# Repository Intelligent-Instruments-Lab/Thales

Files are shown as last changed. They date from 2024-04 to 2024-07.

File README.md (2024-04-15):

# Thales
Software, 3D model and printing files, hardware specs and instructions for building Thales.

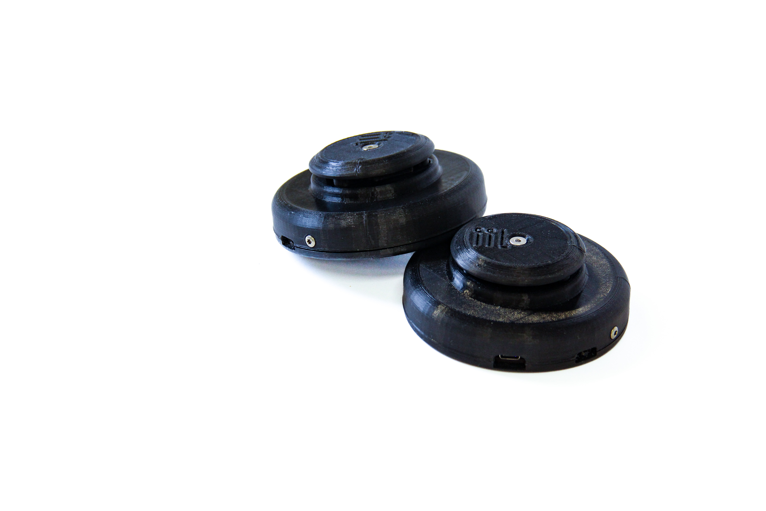
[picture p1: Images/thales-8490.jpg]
  

Hardware: 
- 1x Receiver: I use Esp32 TTGO V7 1.3 Mini - you can use any ESP32 board.
- 2x Sender (on board microcontrollers): Adafruit ESP32 Pico Stemma QT - S2 (avoid S3 due to incompatibility with the BNO055) (https://www.adafruit.com/product/5325)
- 2x Battery Charger shields for Stemma QT (https://www.adafruit.com/product/5397)
- 2x Adafruit BNO055 (https://www.adafruit.com/product/4646)
- Taidacent MLX90393 (with few mods should easily host the Adafruit version)
- 4x Stemma QT I2C wires
- 2x SPDT Switch: https://www.adafruit.com/product/805
- Set of neodymium magnets, 30mm diameter (4mm thick ones, but also 5mm is fine)
- 2x LiPo batteries (I used Makerfocus batteries: https://www.makerfocus.com/products/4pcs-952540-3-7v-1000mah-battery-with-jst1-25-connector-lithium-rechargeable-battery)
- Screws and bolts of various sizes, possibly non ferromagnetic. Importantly, 6x half thread 5M screws, with nuts. Length of the screws should be around 45mm (we cut some 50mm ones):

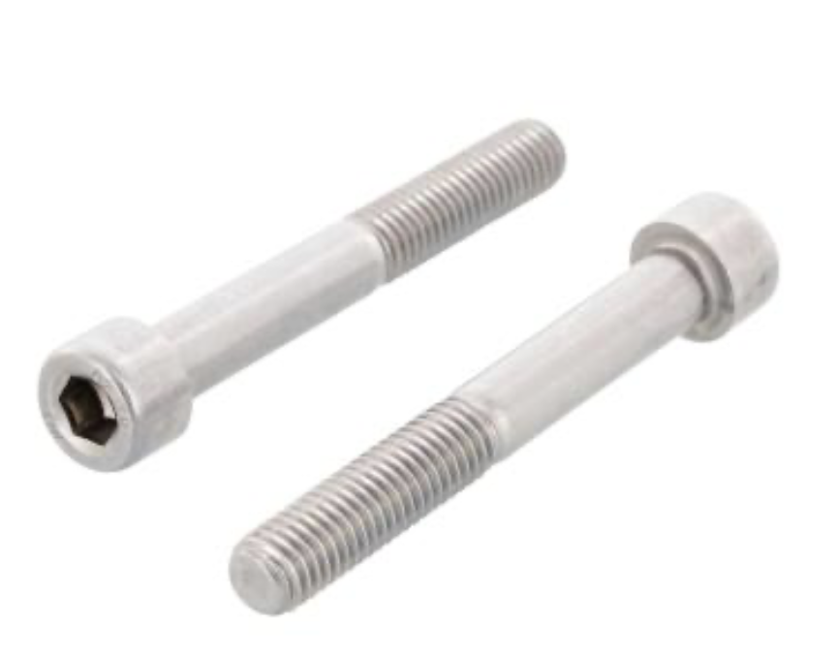
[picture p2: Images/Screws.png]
  

Heres's one assembled controller. The picture is self-explanatory, but I will detail the process as I replicate the instrument in the next weeks:

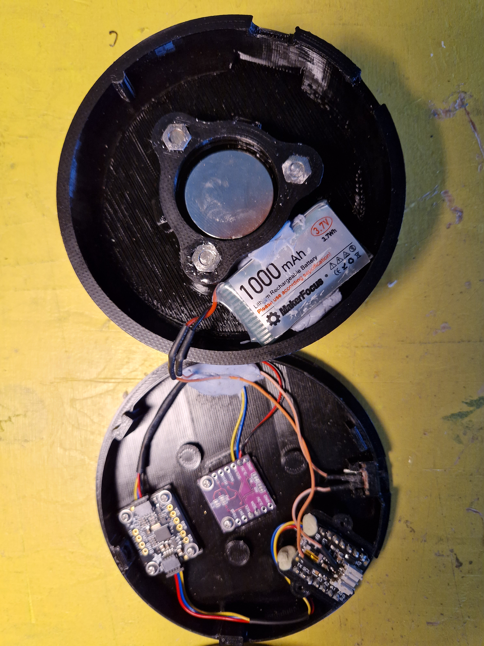
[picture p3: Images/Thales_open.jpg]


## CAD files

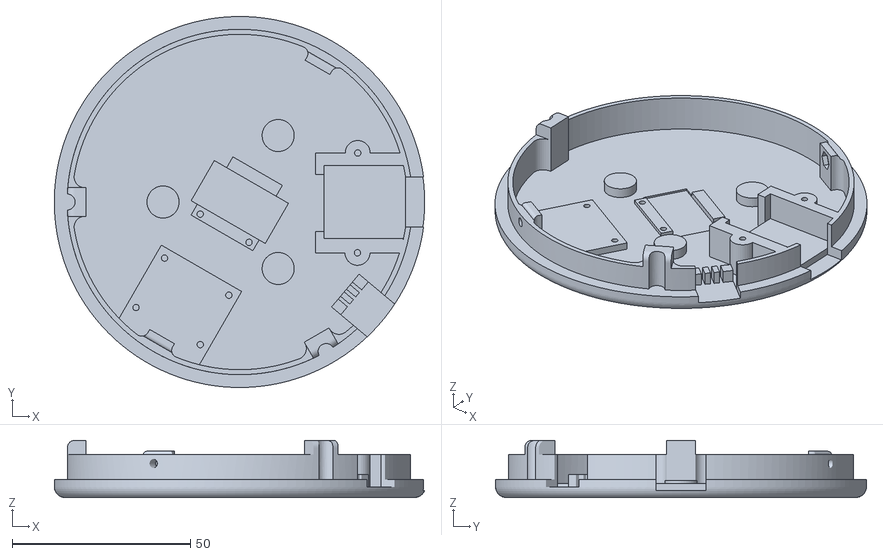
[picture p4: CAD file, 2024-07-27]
Prints/CE3_Box.obj
103.8 x 104.0 x 16.0

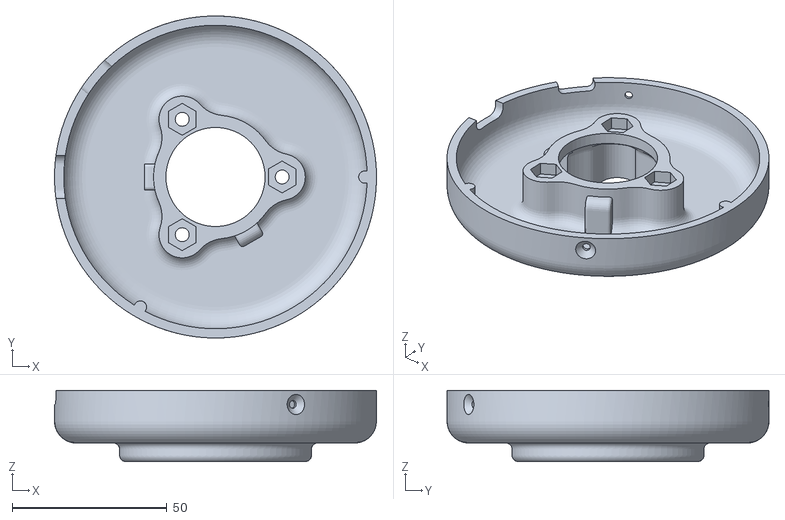
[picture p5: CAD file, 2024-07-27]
Prints/CE3_Lid.obj
104.0 x 104.0 x 23.0

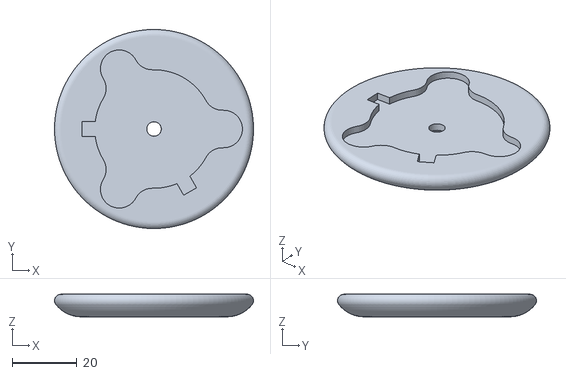
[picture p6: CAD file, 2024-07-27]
Prints/CE3_cap M5.obj
61.5 x 61.5 x 7.00

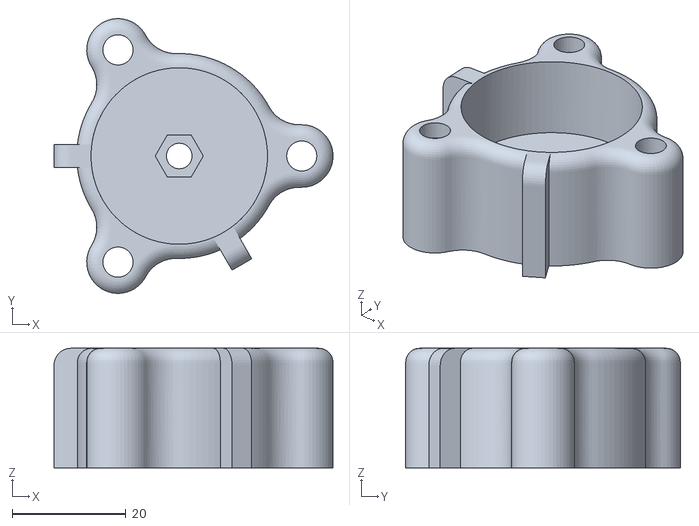
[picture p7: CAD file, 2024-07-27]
Prints/CE3_Riser M5.obj
49.0 x 48.2 x 21.0

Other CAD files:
Thales.f3d

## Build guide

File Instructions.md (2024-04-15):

# magnetic-discs
Software tools, 3D printing files and hardware specs for building a Magnetic Disc. 

Hardware: 
- Receiver: Esp32 TTGO V7 1.3 Mini - you can use any ESP32 board with a decent antenna.
- Sender (on board microcontrollers): Adafruit ESP32 Pico Stemma QT - S2 (avoid S3 due to incompatibility with the BNO055)
- Adafruit BNO055
- Taidacent MLX90393 (with few mods should easily host the Adafruit version)
- Stemma QT I2C wires
- SPDT Switch: https://www.adafruit.com/product/805
- Set of neodymium magnets, 30mm diameter (4mm thick ones, but also 5mm is fine)
- 2 LiPo batteries (I used Makerfocus batteries: https://www.makerfocus.com/products/4pcs-952540-3-7v-1000mah-battery-with-jst1-25-connector-lithium-rechargeable-battery)

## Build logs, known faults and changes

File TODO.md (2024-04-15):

TODO

1 Minor changes to the 3d model, to better accommodate the microcontroller. Now you need to add a 2mm support under the micro to allow plugging the USB-C cable.
2 Add LED with onboard charge indicator (now this is accessible only via sofware).
3 3d model for an optional receiver box. 
2 Experiment with stronger magnets.
3 Example patches.

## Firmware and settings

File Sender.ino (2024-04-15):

/*********
  This instantiates an ESPNow Wifi connection from one Thales controller to the receiver unit.
  Upload as is on the first controller (left hand). When uploading on the second controller change the board ID to 2 (line 162).

  Code is based on Rui Santos ESPNow project at https://RandomNerdTutorials.com/esp-now-many-to-one-esp32/
  
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
  The above copyright notice and this permission notice shall be included in all
  copies or substantial portions of the Software.
*********/

#include <esp_now.h>
#include <Wire.h>
#include <WiFi.h>
#include <Adafruit_BNO055.h>
#include "Adafruit_MLX90393.h"



Adafruit_MLX90393 sensor = Adafruit_MLX90393();
Adafruit_BNO055 bno = Adafruit_BNO055(55, 0x28);
#define MLX90393_CS 10


//timer for transmission freq
unsigned long timer = 0;

// REPLACE WITH THE RECEIVER'S MAC Address
uint8_t broadcastAddress[] = {0x94, 0xB9, 0x7E, 0xD2, 0x14, 0x1C};

// Structure example to send data
// Must match the receiver structure
typedef struct struct_message {
    int id; // must be unique for each sender board
     //magnet
    float hallx; 
    float hally;
    float hallz;     
       //BNO055 angle
    float anglex; 
    float angley; 
    float anglez; 
     //BNO055accelerometer
    float accx;
    float accy;
    float accz; 
    int battery;
   
} struct_message;

// Create a struct_message called myData
struct_message myData;

// Create peer interface
esp_now_peer_info_t peerInfo;

// callback when data is sent
void OnDataSent(const uint8_t *mac_addr, esp_now_send_status_t status) {
  Serial.print("\r\Status:\t");
  Serial.println(status == ESP_NOW_SEND_SUCCESS ? "Success" : "Fail");
}

 
void setup() {
  // Init Serial Monitor
  Serial.begin(115200);

  analogReadResolution(12);

 if (!bno.begin())
  {
    while (1); { delay(10); }
  }

 if (! sensor.begin_I2C()) {       
   while (1) { delay(10); }  
    
  }

 delay(1000);

/* Use external crystal for better accuracy */
bno.setExtCrystalUse(true);
 
//Set gain
sensor.setGain(MLX90393_GAIN_1X);
  
// Set resolution, per axis
sensor.setResolution(MLX90393_X, MLX90393_RES_19);
sensor.setResolution(MLX90393_Y, MLX90393_RES_19);
sensor.setResolution(MLX90393_Z, MLX90393_RES_19);


// Set oversampling
sensor.setOversampling(MLX90393_OSR_2);

// Set digital filtering
sensor.setFilter(MLX90393_FILTER_0);

// Set device as a Wi-Fi Station
WiFi.mode(WIFI_STA);

// Init ESP-NOW
if (esp_now_init() != ESP_OK) {
  Serial.println("Error initializing ESP-NOW");
  return;
   }

  // Once ESPNow is successfully Init, we will register for Send CB to
  // get the status of Trasnmitted packet
  //esp_now_register_send_cb(OnDataSent);
  
  // Register peer
  memcpy(peerInfo.peer_addr, broadcastAddress, 6);
  peerInfo.channel = 0;  
  peerInfo.encrypt = false;
  
  // Add peer        
  if (esp_now_add_peer(&peerInfo) != ESP_OK){
    Serial.println("Failed to add peer");
    return;
  }
}
 
void loop() {

  if((millis()-timer)>5)
  
  {

  int Voltout = analogRead(A2);
  Voltout = Voltout * 5000 / 4096; //read battery charge

 //Get MXL event, normalized to uTesla */
  sensors_event_t event, orientationData, linearAccelData;
  sensor.getEvent(&event); 
  bno.getEvent(&orientationData, Adafruit_BNO055::VECTOR_EULER);
  bno.getEvent(&linearAccelData, Adafruit_BNO055::VECTOR_LINEARACCEL);  


  // Set values to send
  myData.id = 1; //Set ID board number
  myData.hallx = event.magnetic.x;
  myData.hally = event.magnetic.y;
  myData.hallz = event.magnetic.z;
  myData.anglex = orientationData.orientation.x;
  myData.angley = orientationData.orientation.y;
  myData.anglez = orientationData.orientation.z;
  myData.accx = linearAccelData.orientation.x;
  myData.accy = linearAccelData.orientation.y;
  myData.accz = linearAccelData.orientation.z;
  myData.battery = Voltout;

  
 
  // Send message via ESP-NOW
  esp_err_t result = esp_now_send(broadcastAddress, (uint8_t *) &myData, sizeof(myData));
  if (result == ESP_OK) {
    Serial.println("Delivered");
    
  }
  else {
    Serial.println("Error sending the data");
  }
  timer = millis();
  }
}

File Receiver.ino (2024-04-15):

/*********
  This is code instantiates one ESPNow Wifi receiver with the following custom MAC address: 0x94, 0xB9, 0x7E, 0xD2, 0x14, 0x1C
  It matches the sender code on this repo for a total of two Thales controllers.
  Works on any ESP32 board viare serial.
  
  Code is based on Rui Santos EspNow projectat https://RandomNerdTutorials.com/esp-now-many-to-one-esp32/
  
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
  The above copyright notice and this permission notice shall be included in all
  copies or substantial portions of the Software.
*********/

#include <esp_now.h>
#include <WiFi.h>
#include <esp_wifi.h>

// Set your new MAC Address
uint8_t newMACAddress[] = {0x94, 0xB9, 0x7E, 0xD2, 0x14, 0x1C};

// Structure example to receive data
// Must match the sender structure
typedef struct struct_message {
    int id; // must be unique for each sender board
     //
    float hallx; 
    float hally;
    float hallz;     
       //BNO055 angle
    float anglex; 
    float angley; 
    float anglez; 
     //BNO055accelerometer
    float accx;
    float accy;
    float accz;
    int battery;    
}struct_message;

// Create a struct_message called myData
struct_message myData;

// Create a structure to hold the readings from each board (now we have two)
struct_message board1;
struct_message board2;
//struct_message board3;

// Create an array with all the structures (now we have two)
struct_message boardsStruct[2] = {board1, board2};

// callback function that will be executed when data is received
void OnDataRecv(const uint8_t * mac_addr, const uint8_t *incomingData, int len) {
  
  //Get peer MAC address
  //char macStr[18];
  //Serial.print("Packet received from: ");
  //snprintf(macStr, sizeof(macStr), "%02x:%02x:%02x:%02x:%02x:%02x",
  //         mac_addr[0], mac_addr[1], mac_addr[2], mac_addr[3], mac_addr[4], mac_addr[5]);
  //Serial.println(macStr);

  //Copy content incomingData into myData variable
  memcpy(&myData, incomingData, sizeof(myData));

  
  // Update the structures with the new incoming data
  boardsStruct[myData.id-1].hallx = myData.hallx;
  boardsStruct[myData.id-1].hally = myData.hally;
  boardsStruct[myData.id-1].hallz = myData.hallz;
  boardsStruct[myData.id-1].anglex = myData.anglex;
  boardsStruct[myData.id-1].angley = myData.angley;
  boardsStruct[myData.id-1].anglez = myData.anglez;
  boardsStruct[myData.id-1].accx = myData.accx;
  boardsStruct[myData.id-1].accy = myData.accy;
  boardsStruct[myData.id-1].accz = myData.accz;
  boardsStruct[myData.id-1].battery = myData.battery;




  Serial.printf("%u ", myData.id);
  Serial.printf("%.2f ", boardsStruct[myData.id-1].hallx);
  Serial.printf("%.2f ", boardsStruct[myData.id-1].hally);
  Serial.printf("%.2f ", boardsStruct[myData.id-1].hallz);
  Serial.printf("%.2f ", boardsStruct[myData.id-1].anglex);
  Serial.printf("%.2f ", boardsStruct[myData.id-1].angley);
  Serial.printf("%.2f ", boardsStruct[myData.id-1].anglez);
  Serial.printf("%.2f ", boardsStruct[myData.id-1].accx);
  Serial.printf("%.2f ", boardsStruct[myData.id-1].accy);
  Serial.printf("%.2f ", boardsStruct[myData.id-1].accz);
  Serial.printf("%u\r ", boardsStruct[myData.id-1].battery);

}
 
void setup() {
  //Initialize Serial Monitor
  Serial.begin(115200);
  
  //Set device as a Wi-Fi Station
  WiFi.mode(WIFI_STA);

 esp_wifi_set_mac(WIFI_IF_STA, &newMACAddress[0]);

  //Init ESP-NOW
  if (esp_now_init() != ESP_OK) {
    Serial.println("Error initializing ESP-NOW");
    return;
  }
  
  // Once ESPNow is successfully Init, we will register for recv CB to
  // get recv packer info
  esp_now_register_recv_cb(OnDataRecv);
}
 
void loop() {
  // Acess the variables for each board
  /*int board1X = boardsStruct[0].x;
  int board1Y = boardsStruct[0].y;
  int board2X = boardsStruct[1].x;*/

}
